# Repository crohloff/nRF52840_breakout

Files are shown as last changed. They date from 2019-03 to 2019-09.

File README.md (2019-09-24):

# nRF52840_breakout

## Low Cost variant
The low cost variant has four layers but no micro vias, no sensors and different components for the power circuit

## Tool used

 - KiCad 5.0.2

## Custom symbols

 - Custom symbols are placed inside the folder custom_symbols
 - Added as Project Specific Libraries

## Custom footprints

 - Custom footprints are placed inside the folder custom_footprints
 - Added as Project Specific Libraries

## Todo

 -

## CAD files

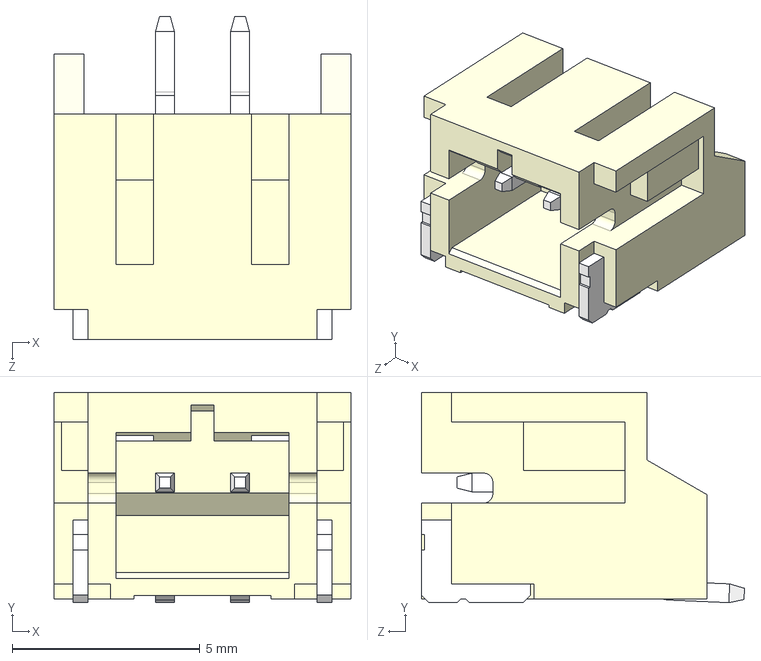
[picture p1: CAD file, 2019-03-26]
custom_3d/JST_PH_S2B-PH-SM4-TB.STEP
7.90 x 5.60 x 8.60 mm

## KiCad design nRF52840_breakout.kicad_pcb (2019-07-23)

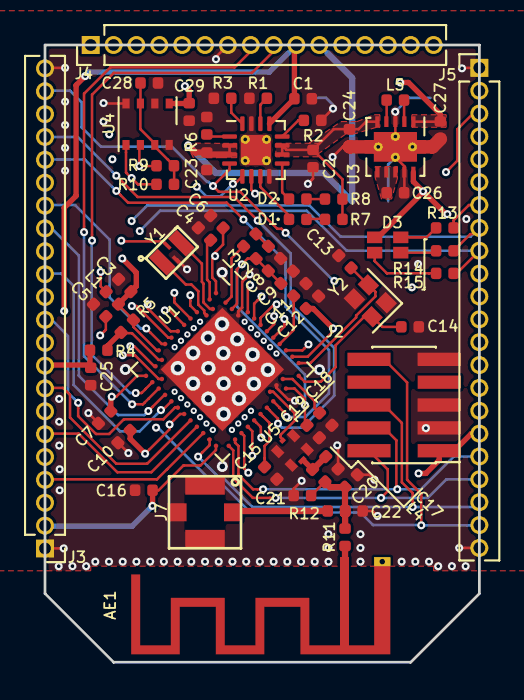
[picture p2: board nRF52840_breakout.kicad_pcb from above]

Board: 4 copper layers, 24.1 x 34.3 mm, 66 parts (1 on the bottom side), 90 nets.

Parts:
AE1: Antenna_Shield; Texas_SWRA117D_2.4GHz_Right
C1, C2, C23, C24, C27: 10µF; C_0402_1005Metric
C3, C5, C7: 4.7µF; C_0402_1005Metric
C4, C10, C12, C16, C28, C29: 100nF; C_0402_1005Metric
C6, C8: 1µF; C_0402_1005Metric
C9: 47nF; C_0402_1005Metric
C11, C19, C21: N.C.; C_0402_1005Metric
C13, C14: 6pF; C_0402_1005Metric
C15: 820pF; C_0402_1005Metric
C17, C20: 1pF; C_0402_1005Metric
C18: 100pF; C_0402_1005Metric
C22: 1.2pF; C_0402_1005Metric
C25: NC; C_0402_1005Metric
C26: 0.1µF; C_0402_1005Metric
D1: GRN; LED_0402_1005Metric
D2: RED; LED_0402_1005Metric
D3: LTST-C19HE1WT
J2: Conn_ARM_JTAG_SWD_10; PinHeader_2x05_P1.27mm_Vertical_SMD
J3, J5: Conn_01x22; PinHeader_1x22_P1.27mm_Vertical
J4: Conn_01x16; PinHeader_1x16_P1.27mm_Vertical
J6: S2B-PH-SM4-TB(LF)(SN); JST_PH_S2B-PH-SM4-TB_LF__SN_
J7: Conn_Coaxial; CON_AMP_A-1JB
L1: NC; L_0402_1005Metric
L2: 15nH; L_0402_1005Metric
L3: 10µH; L_0402_1005Metric
L4: 3.9nH; L_0402_1005Metric
L5: 1.5µH; L_0402_1005Metric
R1: 46.4k; R_0402_1005Metric
R2: 1.18k; R_0402_1005Metric
R3: 1.13k; R_0402_1005Metric
R4: NC; R_0402_1005Metric
R5, R11, R12: 0R; R_0402_1005Metric
R6: 10k; R_0402_1005Metric
R7, R8, R13, R14, R15: 1.5k; R_0402_1005Metric
R9, R10: 4.7k; R_0402_1005Metric
U1: nRF52840; Nordic_AQFN-73-1EP_7x7mm_P0.5mm
U2: BQ24072; VQFN-16-1EP_3x3mm_P0.5mm_EP1.68x1.68mm_ThermalVias
U3: TPS63031; Texas_DRC0010J_ThermalVias
U4: BME680; Bosch_LGA-8_3x3mm_P0.8mm_ClockwisePinNumbering
U5: MM8130-2600RA2; MM8930_2620
Y1: SiT1533; Crystal_SMD_2012-4Pin_2.2mmx1.4mm
Y2: 32MHz-XRCGB32M000F1H00R0; Crystal_SMD_2016-4Pin_2.0x1.6mm

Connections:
D+: J4.8, U1.AD6
D-: J4.9, U1.AD4
GND: AE1.2, C1.2, C2.2, C3.2, C4.2, C5.2, C6.2, C7.2, C8.2, C9.2, C10.2, C11.2, C12.2, C13.1, C14.1, C15.2, C16.2, C17.1, C18.2, C19.2, C20.1, C21.1, C22.2, C23.2, C24.2, C25.2, C26.2, C27.2, C28.1, C29.1, J2.3, J2.5, J2.9, J3.1, J3.22, J4.7, J5.1, J5.22, J6.2, J6.S1, J7.2, R1.2, R2.2, R3.2, R6.1, U1.B7, U1.EP, U1.F23, U2.8, U2.15, U2.17, U3.3, U3.9, U3.11, U4.1, U4.5, U4.7, U5.3, Y1.2, Y2.1, Y2.3
unnamed: AE1.1, R11.1
unnamed: C4.1, U1.C1
unnamed: C5.1, U1.AC5
unnamed: C11.1, U1.A18
unnamed: C13.2, U1.A23, Y2.2
unnamed: C14.2, U1.B24, Y2.4
unnamed: C15.1, U1.N24
unnamed: C17.2, L4.2, U5.2
unnamed: C18.1, U1.D23
unnamed: C8.1, C9.1, C19.1, L2.1, U1.B5, U1.E24
unnamed: C20.2, C21.2, C22.1, L4.1, R11.2, R12.2
unnamed: C26.1, U3.6, U3.7, U3.8
unnamed: D1.1, U2.7
unnamed: D1.2, R7.1
unnamed: D2.1, U2.9
unnamed: D2.2, R8.1
unnamed: D3.1, R13.1
unnamed: D3.2, R14.1
unnamed: D3.3, R15.1
unnamed: J7.1, R12.1
unnamed: L1.2, U1.AB2
unnamed: L2.2, L3.1
unnamed: L3.2, U1.B3
unnamed: L5.1, U3.4
unnamed: L5.2, U3.2
unnamed: R1.1, U2.14
unnamed: R2.1, U2.12
unnamed: R3.1, U2.16
unnamed: R4.1, R5.1, U1.Y2
unnamed: R6.2, U2.1
unnamed: U1.D2, Y1.3
unnamed: U1.F2, Y1.1
unnamed: U1.H23, U5.1
P0.02_AIN0: J4.16, U1.A12
P0.03_AIN1: J3.21, U1.B13, U2.4
P0.04_AIN2: J4.4, U1.J1
P0.05_AIN3: J4.3, U1.K2
P0.06: J4.2, U1.L1
P0.07: J4.1, U1.M2
P0.08: J3.20, U1.N1
P0.09_NFC1: J3.19, U1.L24
P0.10_NFC2: J3.18, U1.J24
P0.11: J3.17, U1.T2
P0.12: J3.16, U1.U1
P0.13: J3.15, U1.AD8
P0.14: J3.14, U1.AC9
P0.15: J3.13, U1.AD10
P0.16: J3.12, U1.AC11
P0.17: J3.11, U1.AD12
P0.19: J3.10, U1.AC15
P0.20: J3.8, U1.AD16
P0.21: J3.7, U1.AC17
P0.22: J3.6, U1.AD18
P0.23: J3.5, U1.AC19
P0.24: J3.4, U1.AD20
P0.25: J3.3, U1.AC21
P0.26: J4.6, U1.G1, U2.6
P0.27: J4.5, U1.H2, U2.5
P0.28_AIN4: J4.15, U1.B11
P0.29_AIN5: J4.14, U1.A10
P0.30_AIN6: J4.13, U1.B9
P0.31_AIN7: J4.12, U1.A8
P1.00_SWO: J2.6, J5.20, U1.AD22
P1.01: J5.16, U1.Y23
P1.02: J5.15, U1.W24
P1.03: J5.14, U1.V23
P1.04: J5.13, U1.U24
P1.05: J5.12, U1.T23
P1.06: J5.11, U1.R24
P1.07: J5.10, U1.P23
P1.08: J5.9, R9.1, R15.2, U1.P2, U4.3
P1.09: J5.8, R10.1, R14.2, U1.R1, U4.4
P1.10: J5.7, R13.2, U1.A20
P1.11: J5.6, U1.B19
P1.12: J5.5, U1.B17
P1.13: J5.4, U1.A16
P1.14: J5.3, U1.B15
P1.15: J5.2, U1.A14
P1.18_RESET: J2.10, J5.21, U1.AC13
SWDCLK: J2.4, J5.18, U1.AA24
SWDIO: J2.2, J5.19, U1.AC24
VBUS_nRF: C1.1, C7.1, J4.10, U1.AD2, U2.13
VDDH: C25.1, J3.9, R4.2
VDDIO: C28.2, R9.2, R10.2, U4.2, U4.6
VDD_BAT: C23.1, J4.11, J6.1, U2.2, U2.3
VDD_nRF: C3.1, C6.1, C10.1, C12.1, C16.1, C27.1, C29.2, D3.4, J2.1, J3.2, J5.17, L1.1, R5.2, U1.A22, U1.AD14, U1.AD23, U1.B1, U1.W1, U3.1, U3.10, U4.8, Y1.4
V_SYS: C2.1, C24.1, R7.2, R8.2, U2.10, U2.11, U3.5

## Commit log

2019-03-22 added custom antenna footprints
2019-03-22 custom footprint for coax connector with switch
    [nRF52840_breakout.sch]
2019-03-24 usb-c custom footprint and 3d model
2019-03-24 changed crystal load capacitance according to component / minor changes
    [nRF52840_breakout.sch, nRF52840_breakout_connector.sch, nRF52840_breakout_power.sch]
2019-03-24 switched nfc antenna connector
    [CONNECTOR_FFC_1734592-5.stp, nRF52840_breakout.sch, nRF52840_breakout_connector.sch]
2019-03-26 switched battery connector
    [JST_PH_S2B-PH-SM4-TB.STEP]
2019-03-26 minor changes to schematic and layout
    [nRF52840_breakout.sch, nRF52840_breakout_connector.sch, nRF52840_breakout_power.sch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]
2019-04-18 added som like version of the breakout
    [nRF52840_breakout.kicad_pcb, nRF52840_breakout.sch, nRF52840_breakout_connector.sch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]
2019-04-25 path selection/charging/bme680 sensor integration
    [nRF52840_breakout.kicad_pcb, nRF52840_breakout.sch, nRF52840_breakout_connector.sch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]
2019-05-02 add u.fl conn footprint
2019-05-02 add SiT1533 footprint
2019-05-02 add rgb led footprint and symbol
2019-05-02 minor changes / switched from tag - 10pol debug connector
    [nRF52840_breakout.kicad_pcb, nRF52840_breakout.sch, nRF52840_breakout_connector.sch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]
2019-05-02 changed pin 3/11 to passive
2019-05-02 layout / added part details etc
    [nRF52840_breakout.kicad_pcb, nRF52840_breakout.sch, nRF52840_breakout_connector.sch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]
2019-07-23 clean up silk, fab
    [nRF52840_breakout.kicad_pcb]
2019-07-23 clean up
    [CONNECTOR_FFC_1734592-5.stp]
